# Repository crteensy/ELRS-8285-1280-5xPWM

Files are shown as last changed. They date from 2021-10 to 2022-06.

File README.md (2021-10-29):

# ELRS-8285-1280-5xPWM
ELRS receiver with an SX1280/1281 and 5 PWM outputs, based on the ESP8285.

see https://github.com/ExpressLRS/ExpressLRS/pull/998 for what happened earlier.

- First revision for easy manual assembly: no passives smaller than 0402, single sided.
- LEDs for power (5V, 3V3) and one for ELRS
- uFl footprint, but the Molex turret should fit as well
- simple PCB trace antenna for WiFi
- initial flashing can be done through the servo header (I think)

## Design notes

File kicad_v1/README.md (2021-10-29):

# ELRS-8285-1280-5xPWM / KiCad prototype

## This is the prototype design for this receiver
- single sided assembly
- passives 0402 or larger

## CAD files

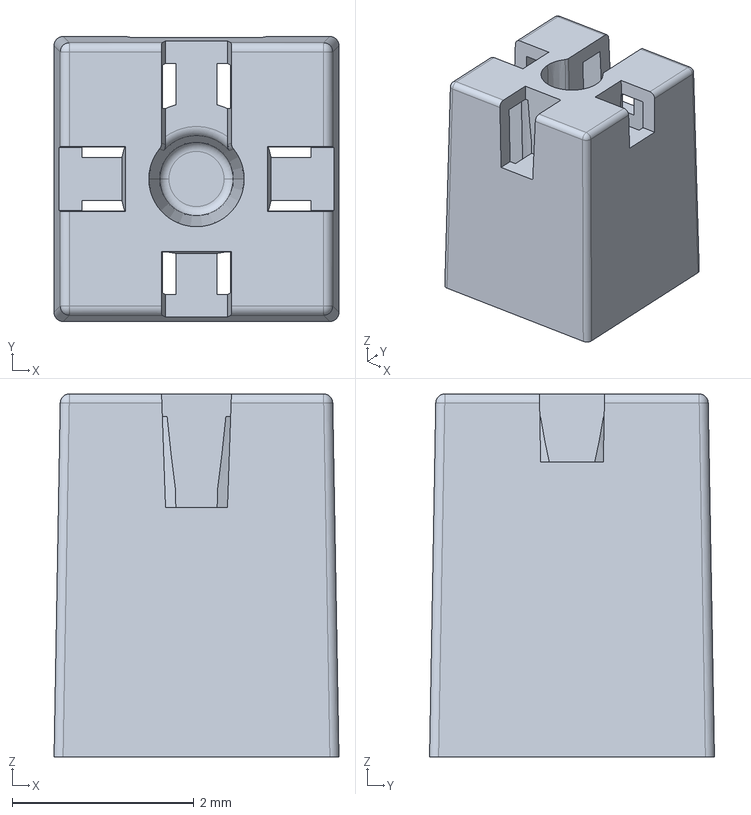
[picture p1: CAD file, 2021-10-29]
kicad_v1/3d_local/479480001.stp
3.14 x 3.14 x 4.00 mm

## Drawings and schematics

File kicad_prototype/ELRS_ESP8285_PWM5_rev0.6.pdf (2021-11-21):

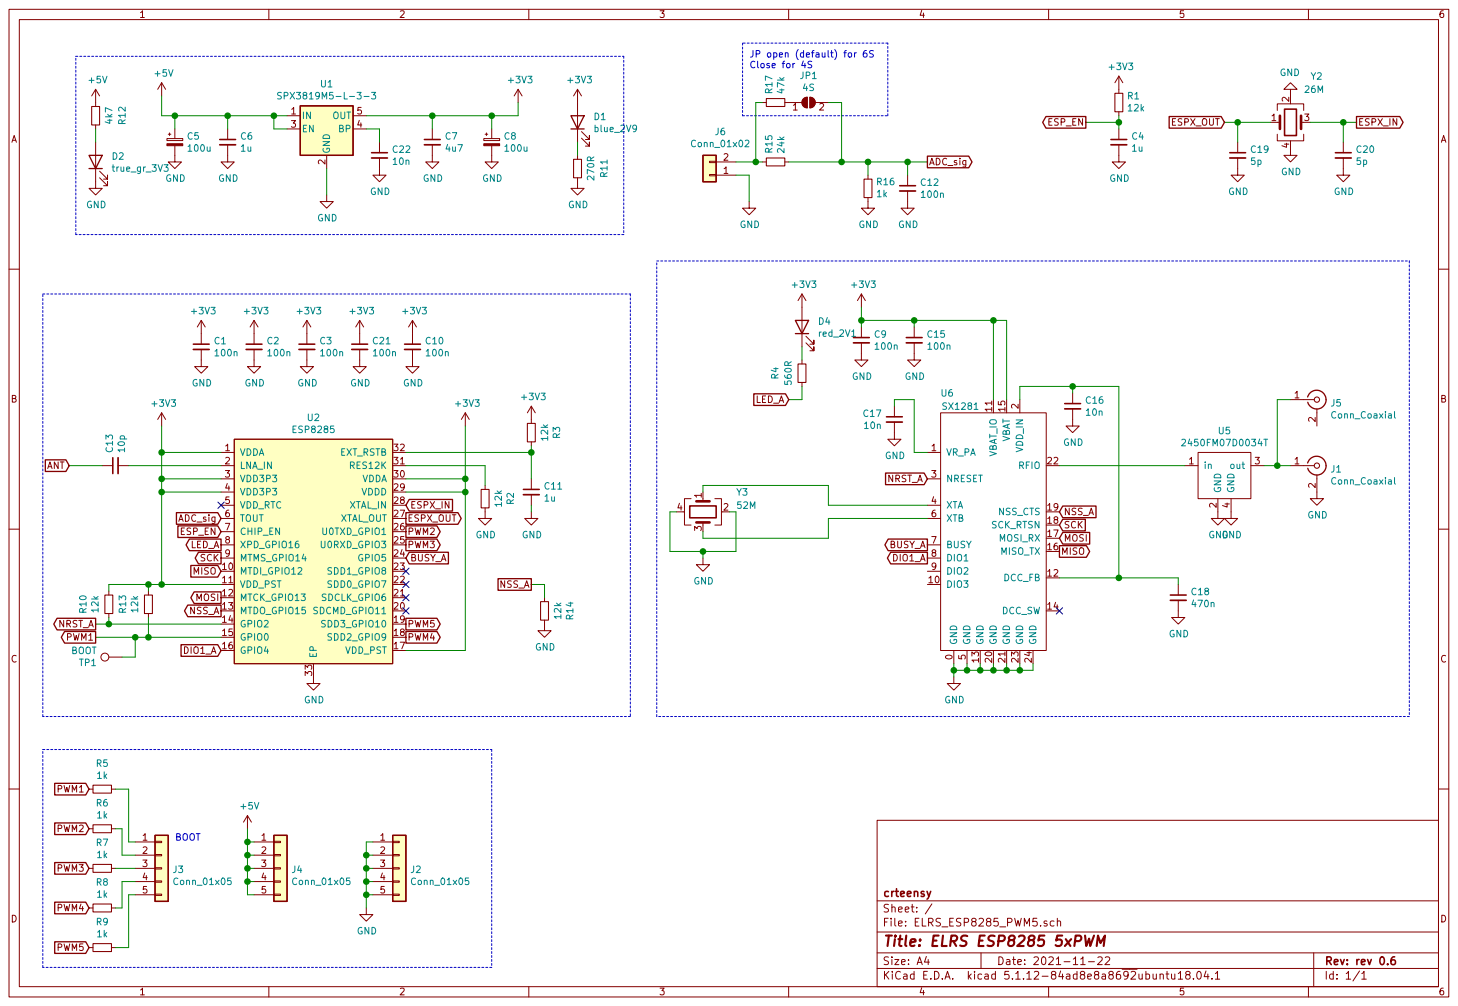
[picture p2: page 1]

JP open (default) for 6S Close for 4S

2 EN 3 BP 4 OUT 5 U1 SPX3819M5-L-3-3 GND GND GND GND GND

File: ELRS_ESP8285_PWM5.sch Sheet: / crteensy R4 560R GND

2 GND 20 GND 21 RFIO 22 GND 23 GND 24 NRESET 3 XTA 4 GND

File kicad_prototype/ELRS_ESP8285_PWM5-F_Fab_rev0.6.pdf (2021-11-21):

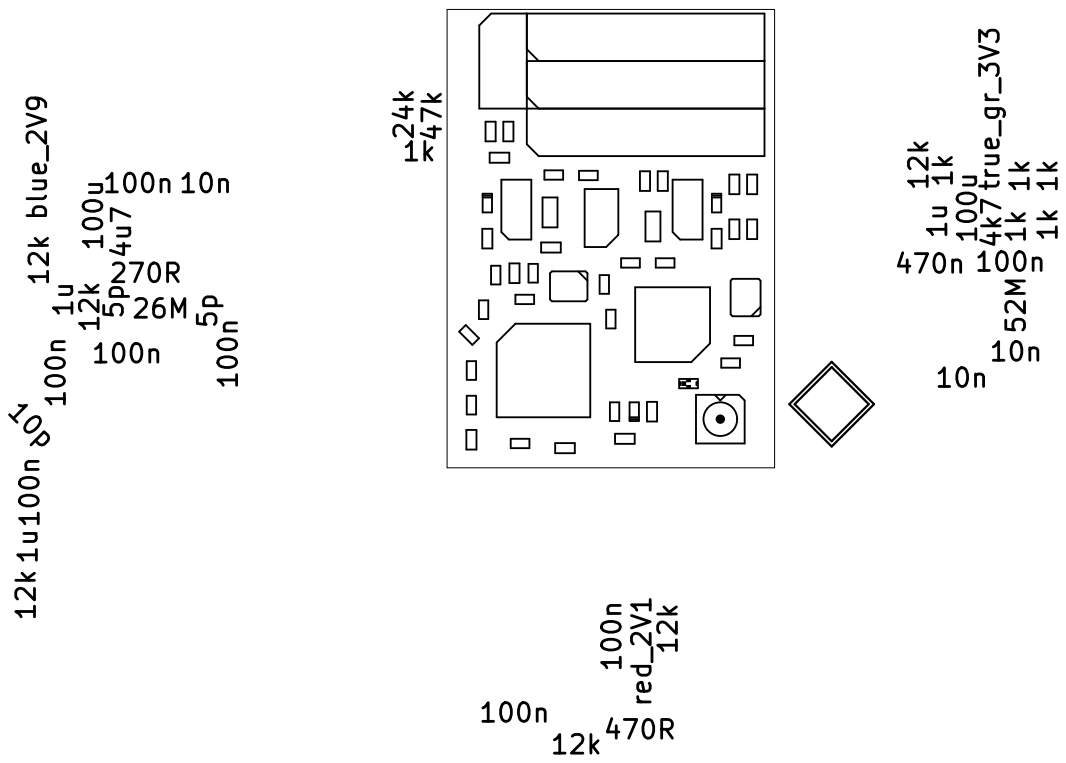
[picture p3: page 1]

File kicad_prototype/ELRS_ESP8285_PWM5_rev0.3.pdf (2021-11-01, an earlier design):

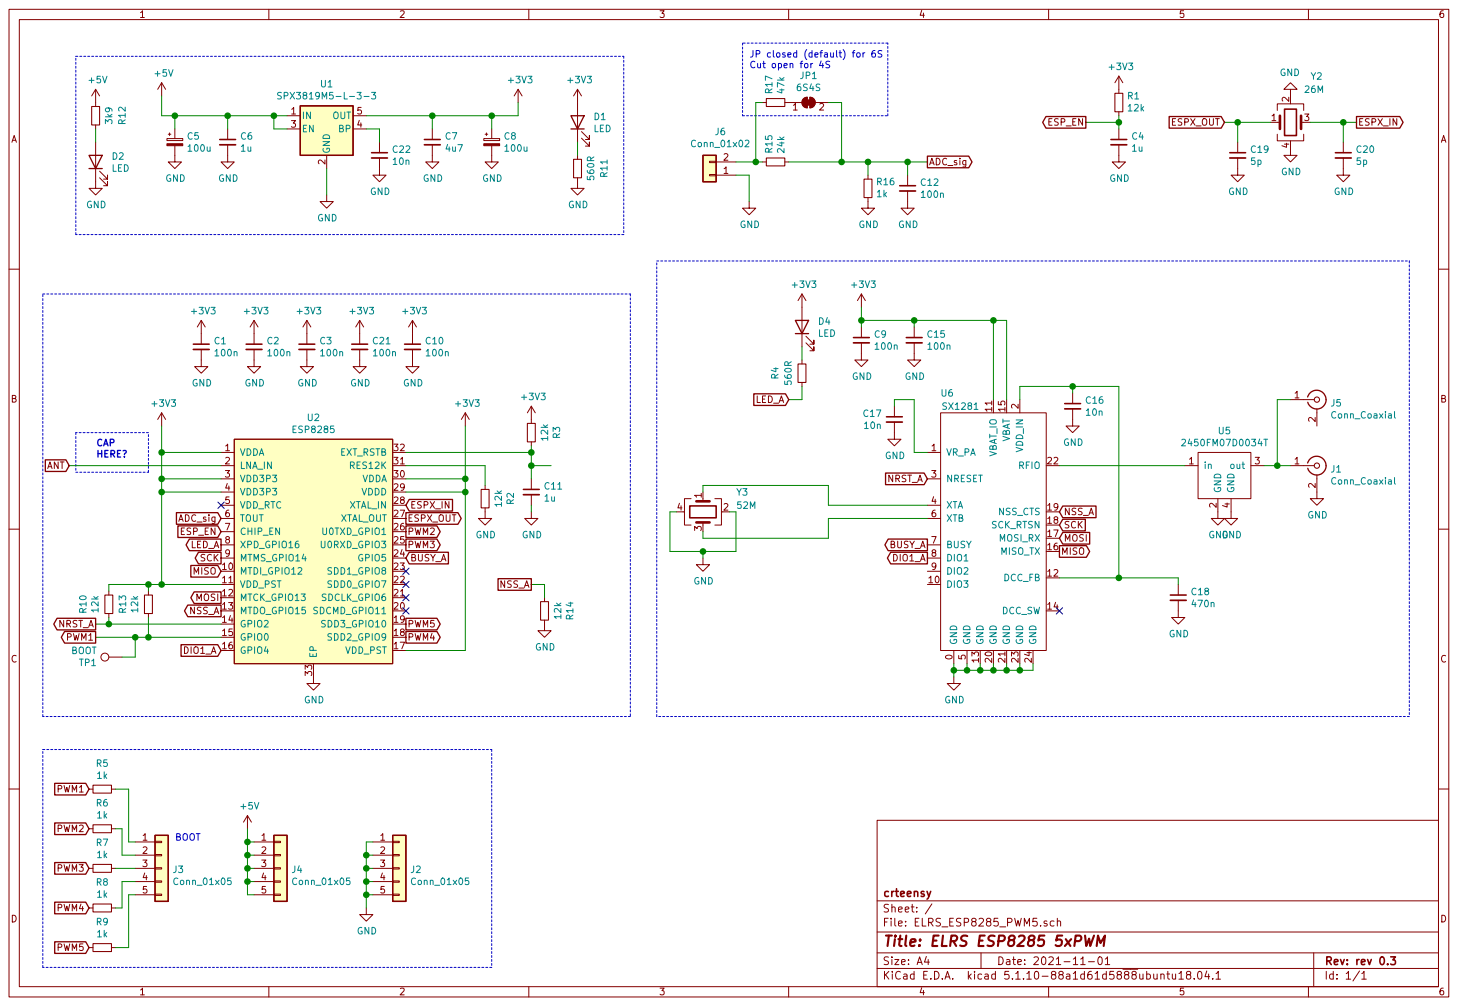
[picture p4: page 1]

JP closed (default) for 6S

5 XTB 6 BUSY 7 DIO1 8 DIO2 9 U6SX1281 +5V GND 3k9 R12 GND

2 GND 20 GND 21 RFIO 22 GND 23 GND 24 NRESET 3 XTA 4 GND

File: ELRS_ESP8285_PWM5.sch Sheet: / crteensy R9

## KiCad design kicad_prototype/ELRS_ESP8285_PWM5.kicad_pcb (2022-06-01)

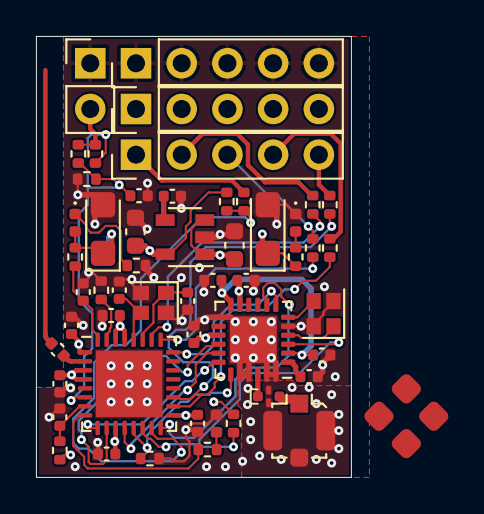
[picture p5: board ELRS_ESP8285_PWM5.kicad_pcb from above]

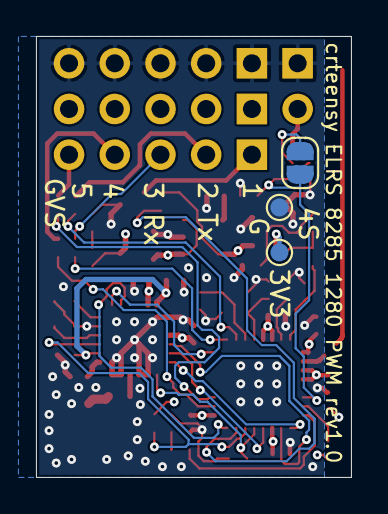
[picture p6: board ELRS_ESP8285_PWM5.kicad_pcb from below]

Board: 4 copper layers, 17.5 x 24.5 mm, 56 parts (3 on the bottom side), 40 nets.

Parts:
C1, C2, C3, C9, C10, C12, C15, C21: 100n; C_0402_1005Metric
C4, C11: 1u; C_0402_1005Metric
C5, C8: 100u; CP_EIA-3216-18_Kemet-A
C6: 1u; C_0603_1608Metric
C7: 4u7; C_0603_1608Metric
C13: 10p; C_0402_1005Metric
C16, C17, C22: 10n; C_0402_1005Metric
C18: 470n; C_0402_1005Metric
C19, C20: 4p7; C_0402_1005Metric
D1: blue_2V9; LED_0402_1005Metric
D2: true_gr_3V3; LED_0402_1005Metric
D4: red_2V1; LED_0402_1005Metric
J1: Conn_Coaxial; U.FL_Molex_MCRF_73412-0110_Vertical_dense
J2, J3, J4: Conn_01x05; PinHeader_1x05_P2.54mm_Vertical
J5: Conn_Coaxial; molex_479480001_2g4-turret
J6: Conn_01x02; PinHeader_1x02_P2.54mm_Vertical
JP1: 4S; SolderJumper-2_P1.3mm_Open_RoundedPad1.0x1.5mm
R1, R2, R3, R10, R13, R14: 12k; R_0402_1005Metric
R4: 560R; R_0402_1005Metric
R5, R6, R7, R8, R9, R16: 1k; R_0402_1005Metric
R11: 270R; R_0402_1005Metric
R12: 4k7; R_0402_1005Metric
R15: 24k; R_0402_1005Metric
R17: 47k; R_0402_1005Metric
TP1, TP2: TestPoint; TestPoint_Pad_D1.0mm
U1: SPX3819M5-L-3-3; SOT-23-5
U2: ESP8285; QFN-32-1EP_5x5mm_P0.5mm_EP3.7x3.7mm_dense
U5: 2450FM07D0034T
U6: SX1281; QFN-24-1EP_4x4mm_P0.5mm_EP2.6x2.6mm_SX1280_dense
Y2: 26M; Crystal_SMD_2016-4Pin_2.0x1.6mm
Y3: 52M; Crystal_SMD_2016-4Pin_2.0x1.6mm

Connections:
+3V3: C1.1, C2.1, C3.1, C7.1, C8.1, C9.1, C10.1, C15.1, C21.1, D1.2, R1.2, R3.2, R10.2, R13.2, TP1.1, U1.5, U2.1, U2.3, U2.4, U2.11, U2.17, U2.29, U2.30, U6.11, U6.15
+5V: C5.1, C6.1, J4.1, J4.2, J4.3, J4.4, J4.5, R12.1, U1.1, U1.3
ADC_sig: C12.1, JP1.2, R15.1, R16.2, U2.6
BUSY_A: U2.24, U6.7
DIO1_A: U2.16, U6.8
ESPX_IN: C20.1, U2.28, Y2.3
ESPX_OUT: C19.1, U2.27, Y2.1
ESP_EN: C4.1, R1.1, U2.7
GND: C1.2, C2.2, C3.2, C4.2, C5.2, C6.2, C7.2, C8.2, C9.2, C10.2, C11.2, C12.2, C15.2, C16.2, C17.2, C18.2, C19.2, C20.2, C21.2, C22.2, D2.1, D4.1, J1.2, J2.1, J2.2, J2.3, J2.4, J2.5, J6.1, R2.1, R11.2, R14.1, R16.1, TP2.1, U1.2, U2.33, U5.2, U5.4, U6.0, U6.5, U6.13, U6.20, U6.21, U6.23, U6.24, Y2.2, Y2.4, Y3.2, Y3.4
LED_A: R4.1, U2.8
MISO: U2.10, U6.16
MOSI: U2.12, U6.17
NRST_A: R10.1, U2.14, U6.3
NSS_A: R14.2, U2.13, U6.19
unnamed: C11.1, R3.1, U2.32
unnamed: C13.2, U2.2
unnamed: C16.1, C18.1, U6.2, U6.12
unnamed: C17.1, U6.1
unnamed: C22.1, U1.4
unnamed: D1.1, R11.1
unnamed: D2.2, R12.2
unnamed: D4.2, R4.2
unnamed: J1.1, J5.1, U5.3
unnamed: J3.1, R5.1
unnamed: J3.2, R6.1
unnamed: J3.3, R7.1
unnamed: J3.4, R8.1
unnamed: J3.5, R9.1
unnamed: J6.2, R15.2, R17.2
unnamed: JP1.1, R17.1
unnamed: R2.2, U2.31
unnamed: U5.1, U6.22
unnamed: U6.4, Y3.1
unnamed: U6.6, Y3.3
PWM1: R5.2, R13.1, U2.15
PWM2: R6.2, U2.26
PWM3: R7.2, U2.25
PWM4: R8.2, U2.18
PWM5: R9.2, U2.19
SCK: U2.9, U6.18

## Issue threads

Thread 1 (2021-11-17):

Rx LED is inverted

crteensy, 2021-11-17:
In the current revision, the LED is inverted (active low). Change to active high.

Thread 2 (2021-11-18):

Fix LED current limiting resistors after initial testing

crteensy, 2021-11-18:
Initial testing with
- 5V LED: true green, V_F = 3.3V, R = 4.7 kOhm
- 3V3 LED: blue, V_F = 2.9 V, R = 330 Ohm
- Rx LED: red, V_F = 2.1 C, R = 470 Ohm

crteensy, 2021-11-22:
Should be good now.

Closed 2021-11-22.

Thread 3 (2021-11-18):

schematic: GPIO0 and GPIO2 wiring is ugly

crteensy, 2021-11-18:
fix that with direct wires to 3V3

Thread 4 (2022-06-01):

Does sx1281 work?

zhuwei, 2022-06-01:

crteensy, 2022-06-01:
Yes, for now.

ELRS currently doesn't use the SX1280's ranging features, and they are the only difference between '80 and' 81. In fact many receivers are currently built with the '81.

There are no plans to use ranging features in the foreseeable future (at least that's what I understood from discussions in the ELRS discord) so if you want to build this and only have the' 81, go for it.

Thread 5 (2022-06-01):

Can you provide Gerber file?

zhuwei, 2022-06-01:

zhuwei, 2022-06-01:
If only you could provide a physical picture

crteensy, 2022-06-01:
Sure I can provide gerbers - which PCB manufacturer would you use? They have slightly different preferences for the settings

The ESP8285 antenna is the straight PCB trace antenna along the left edge in this screenshot:
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

crteensy, 2022-06-01:
Little heads up: I just updated the repo

zhuwei, 2022-06-02:
I willI intend to use eda/jlc supplier(www.jlc.com).
thks!

crteensy, 2022-06-02:
See if these are ok for you (PCB rev 0.6)

[ELRS_ESP8285_PWM5_rev0.6-jlcpcb.zip](https://github.com/crteensy/ELRS-8285-1280-5xPWM/files/8827708/ELRS_ESP8285_PWM5_rev0.6-jlcpcb.zip)

zhuwei, 2022-06-04:
Thank you very much!

Closed 2022-06-04.

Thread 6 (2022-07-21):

Unable to burn firmware for esp8285

zhuwei, 2022-07-21:
I detected that the voltage of 3.3V was normal, and pwm1 was also connected to GND.
How else do I need to test?

zhuwei, 2022-07-23:
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

zhuwei, 2022-07-23:
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

crteensy, 2022-07-23:
During power-up, the ESP's boot pin must be pulled high or low (can't look it up because I'm on vacation). You can do that with a female-female cable on the servo header. Look up the boot pin in the schematic to see which pwm output that is

zhuwei, 2022-07-25:
I tested it with a multimeter，boot pin has be pulled low, and TX and Rx are also the same as pwm2 and 3.
But I made three, but I still can't burn them.
sorry, I'm ready to give up

crteensy, 2022-07-25:
Don't give up! Are you on the elrs discord? There we can help in a much more interactive manner

crteensy, 2025-03-12:
I don't remember exactly tbh, I'll investigate

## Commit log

2021-10-29 move pogo pad to boot input, minor layout changes
    [ELRS_ESP8285_PWM5.kicad_pcb, ELRS_ESP8285_PWM5.sch]
2021-10-30 layout work
    [ELRS_ESP8285_PWM5.kicad_pcb]
2021-11-01 schematic/layout rev0.3
    [ELRS_ESP8285_PWM5.sch, ELRS_ESP8285_PWM5_rev0.3.kicad_pcb, ELRS_ESP8285_PWM5_ufl_20211028.kicad_pcb]
2021-11-01 add series cap to antenna trace
    [ELRS_ESP8285_PWM5.kicad_pcb]
2022-06-01 general update
    [479480001.stp, ELRS_ESP8285_PWM5.kicad_pcb, ELRS_ESP8285_PWM5.kicad_sch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]
